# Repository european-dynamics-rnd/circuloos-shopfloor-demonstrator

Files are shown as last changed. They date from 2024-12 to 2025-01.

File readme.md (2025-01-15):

# CIRCULOOS Shopfloor Demo

The current repo is a collection of hardware and software compoment ment to simulate the jurney of the measurements of a shopfloor to a local RAMP IIoT instance (on a RasberyPi) and on the centalazed CIRCULOOS Data platform.
The demo consist of a full end to end solution ie from the sensor to the communication inside the shopfloor to the local RAMP IIoT instance and to the centalazed CIRCULOOS Data platform.

# Troubleshoot
See Troubleshoot

## Measurements
The following measurements (from various sensors) are included:
- Air temperature (BME680)
- Air hummidity (BME680)
- Air presure (BME680)
- Surface temperature (Pt100, k-type thermocuple)
- Inductive proximity sensor
- Weight
- Colour

## Shopfloor communication protocols 
The following communication protocols are incuded:
- CAN
- RS485 
- MQTT 
- I2C

# Sensor nodes 

The base embeded computational unit for each node is the module based on ESP32 by Olimex.

A list of the different node with each sensor can be foound on [system.md](./system.md)

## Diagram
diagram

# Demos

## sensor_node_1_scale_and_colour_over_RS485

The sensor node/ESP32  is designed to simulate a station that measures the weight and identifies the color of an item. It consists of an LCD, two buttons, a scale, and color sensors.

The user begins the procedure by pressing a button to activate the color sensor. They then position the sensor over the material to be identified. The detected color will be displayed on the LCD. Once the user finalizes the procedure, they release the button.

Next, the material (up to 1 kg) is placed on the scale. After waiting for the measurement to stabilize, the user gently presses the button.

The data is then sent via RS-485 to the Raspberry Pi. An python script reads the data from the serial and transform it on a NGSI-LD entity where it becomes available on the local CIRCULOOS data platform.

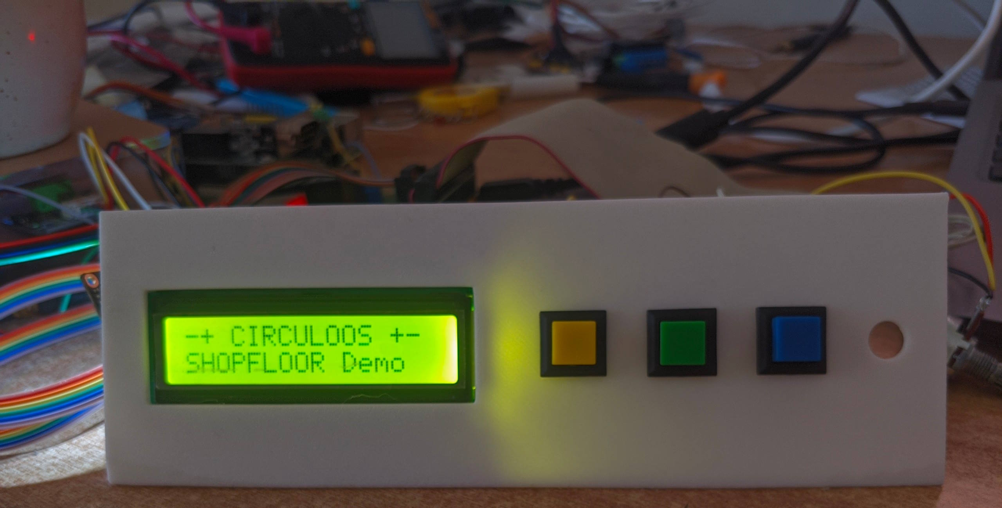
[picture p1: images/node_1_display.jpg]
node_1_display

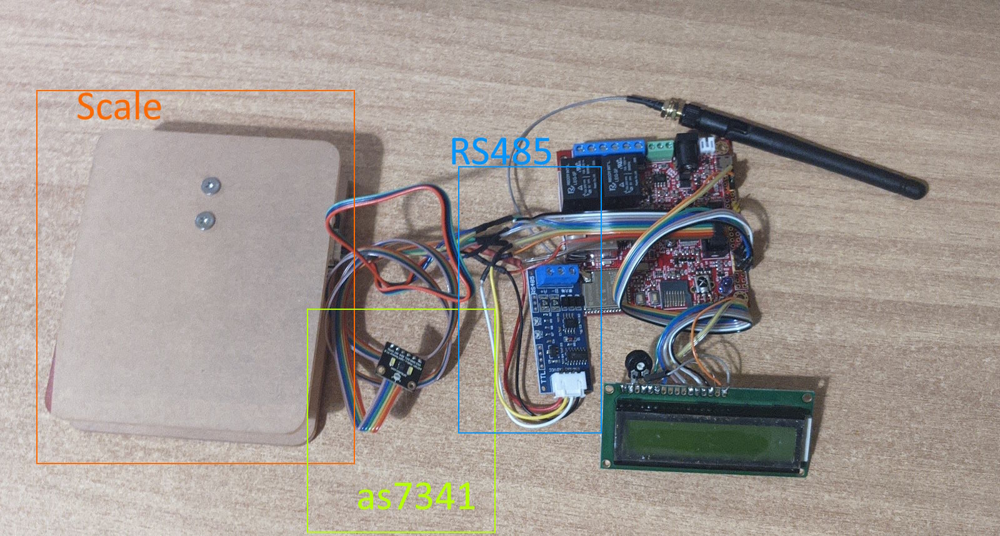
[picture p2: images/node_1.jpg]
node_1


## sensor_node_2_environmental_over_wifi

The node/ESP32 reads the external BME680 sensor via I2C every 10min, transform the measurements into a json and send it to a local MQTT Broker, running on the RasberyPi.
The json message it is read by the IoTAgent and becomes avalable to the local CIRCULOOS data platform. 

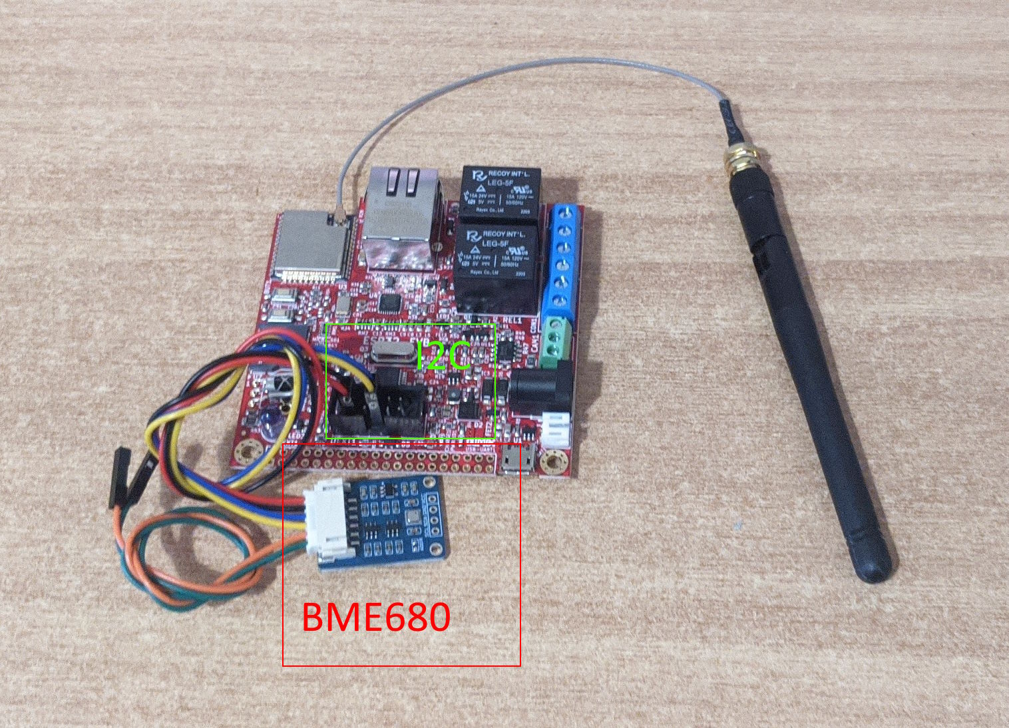
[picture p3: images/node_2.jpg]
node_2


## sensor_node_3_temperature_over_can

The node/ESP32 reads the external Pt100 and a K-type thermocouple every 10min, and sends the measurements via CAN bus to the Raspberry Pi. 

An python script reads the data from the serial and transform it on a NGSI-LD entity where it becomes available on the local CIRCULOOS data platform.

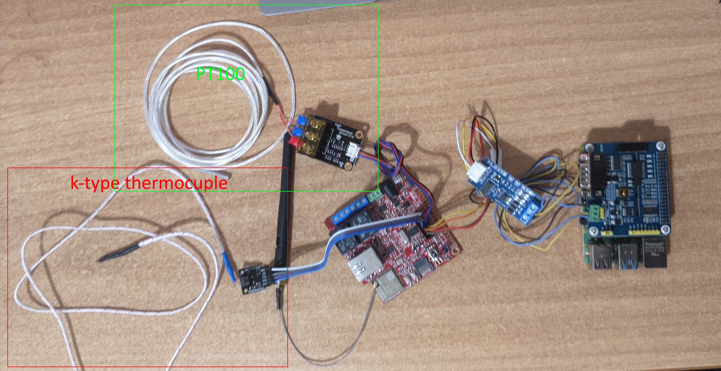
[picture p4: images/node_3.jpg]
node_3


<br />
<br />
<br />
<br />

Copyright © 2023-2024 European Dynamics Luxembourg S.A.

Licensed under the EUPL, Version 1.2.
You may not use this work except in compliance with the License.
You may obtain a copy of the License at https://joinup.ec.europa.eu/collection/eupl/eupl-text-eupl-12 

Unless required by applicable law or agreed to in writing, software distributed under the License is distributed on an "AS IS" BASIS,
WITHOUT WARRANTIES OR CONDITIONS OF ANY KIND, either express or implied. See the License for the specific language governing permissions and limitations under the License.

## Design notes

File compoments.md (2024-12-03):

# Main computation unit
## RaspberryPi  5
https://grobotronics.com/raspberry-pi-5-8gb.html  or https://www.hellasdigital.gr/go-create/raspberry-and-accessories/raspberry-pi-5-and-accessories/raspberry-pi-5/raspberry-pi-5-8gb/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
https://grobotronics.com/aluminum-case-for-raspberry-pi-5-temperature-controlled-fan.html

**OR** 

## RaspberryPi  4
https://grobotronics.com/raspberry-pi-4-model-b-8gb.html
https://grobotronics.com/case-for-raspberry-pi-4-with-cooling-fan-black-clear.html

## RasberyPi misc
https://grobotronics.com/hdmi-to-micro-hdmi-male-1.8m-black.html
https://grobotronics.com/power-supply-for-raspberry-pi-5-27w-type-c.html
https://grobotronics.com/sandisk-ultra-microsdxc-128gb-class-10-140mb-s-sd-adapter.html

# ESP32 modules
https://www.olimex.com/Products/IoT/ESP32/ESP32-EVB/open-source-hardware ESP32-EVB-EA-IND  x4

# sensors
https://grobotronics.com/fermion-as7341-11-channel-visible-light-sensor.html
https://grobotronics.com/inductive-proximity-sensor-12mm-lj12a3-4-z-ex.html

# Temperature sensors

https://grobotronics.com/waveshare-environmental-sensor-bme680.html x4

https://grobotronics.com/gravity-analog-high-temperature-sensor-30350c.html
https://grobotronics.com/pimoroni-mcp9600-thermocouple-amplifier-breakout.html
https://grobotronics.com/pimoroni-braided-k-type-thermocouple.html

# Scale
https://grobotronics.com/gravity-i2c-1kg-weight-sensor-kit-hx711.html

# CAN bus
https://www.waveshare.com/product/2-ch-can-hat-plus.htm
https://www.hellasdigital.gr/go-create/raspberry-and-accessories/raspberry-pi-4-and-accessories/2-channel-isolated-can-expansion-hat-for-raspberry-pi-board/

# RS485 modules
https://grobotronics.com/waveshare-isolated-rs485-rs232-hat-spi-control.html
https://grobotronics.com/ttl-to-rs485-module.html x3

# Misc
https://grobotronics.com/dc-power-plug-5.5-x-2.1mm-barrel-plugable-screw-terminal.html  x4
https://grobotronics.com/hook-up-wire-22awg-0.32mm2-assortment-stranded.html
https://grobotronics.com/power-supply-5vdc-2a-clw-eb-output-5.5x2.1.html x4

# Current sensor
https://grobotronics.com/gravity-analog-ac-current-sensor-10a.html

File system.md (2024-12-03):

# RAMP IIoT computer

## Components 
- RaspberryPi 5 8GB
- Power supply 
- Case with fun
- SD card
## Communication interfaces
- RS485 ([waveshare](https://grobotronics.com/waveshare-isolated-rs485-rs232-hat-spi-control.html))
- CAN bus ([waveshare](https://www.waveshare.com/product/2-ch-can-hat-plus.htm))

### Optimal
HDMI to micro

# Sensor Node #1 scale and colour  - RS485/Modubus
- ESP32 ([olimex](https://www.olimex.com/Products/IoT/ESP32/ESP32-EVB/open-source-hardware))
- Scale kit ([gravity](https://grobotronics.com/gravity-i2c-1kg-weight-sensor-kit-hx711.html))
- Color sensors ([AS7341](https://grobotronics.com/fermion-as7341-11-channel-visible-light-sensor.html))
- TTL to RS485 module ([module](https://grobotronics.com/ttl-to-rs485-module.html))

# Sensor Node #2 Environmental mqtt over wifi
- ESP32 ([olimex](https://www.olimex.com/Products/IoT/ESP32/ESP32-EVB/open-source-hardware))
- Temperature, RH, Barometric Pressure ([BME680](https://grobotronics.com/waveshare-environmental-sensor-bme680.html) )
- PT1000 ([module](https://grobotronics.com/gravity-analog-high-temperature-sensor-30350c.html))
- K-type thermocouple ([modeule](https://grobotronics.com/pimoroni-mcp9600-thermocouple-amplifier-breakout.html))

# Sensor Node #3 Temperature - CAN bus
- ESP32 ([olimex](https://www.olimex.com/Products/IoT/ESP32/ESP32-EVB/open-source-hardware))
- PT1000 ([module](https://grobotronics.com/gravity-analog-high-temperature-sensor-30350c.html))
- K-type thermocouple ([modeule](https://grobotronics.com/pimoroni-mcp9600-thermocouple-amplifier-breakout.html))
- Inductive Proximity ([module](https://grobotronics.com/inductive-proximity-sensor-12mm-lj12a3-4-z-ex.html))

# Sensor Node #4 - OPC UA Server over wifi
- ESP32 ([olimex](https://www.olimex.com/Products/IoT/ESP32/ESP32-EVB/open-source-hardware))
- Temperature, RH, Barometric Pressure ([BME680](https://grobotronics.com/waveshare-environmental-sensor-bme680.html) )

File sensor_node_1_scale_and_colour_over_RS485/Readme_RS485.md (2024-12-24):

# RS485 encoding

For the demo a easy encoding schme is used for the transfer of data from the ESP32 to the rasberryPI.

## for scale and colour sensors, type 1

Message: #1;weight_in_gr;as7341_ADF2;as7341_ADF4;as7341_ADF3;as7341_ADF5;as7341_ADF7;as7341_ADF8;as7341_ADCLEAR;as7341_ADF6;as7341_ADNIR#

see [sample_data.txt](./sample_data.txt) for more examples.

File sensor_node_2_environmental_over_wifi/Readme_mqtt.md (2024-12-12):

# Connecting a MQTT topic with Agent
The MQTT topic that listen is /json/BME680KEYas32r/node-002/attrs so /json/<<apikey>>/<<device_id>>/attrs

apikey is set on [provisioning_service.sh](../circuloos-data-platform/nodes/provisioning_service.sh) from on the circuloos-data-platform ie BME680KEYas32r
device_id ie node-002

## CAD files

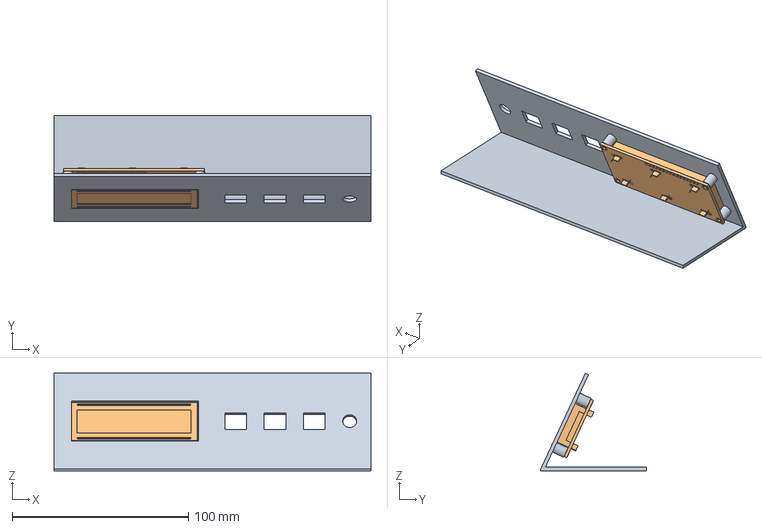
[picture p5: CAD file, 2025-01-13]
sensor_node_1_scale_and_colour_over_RS485/3d_model/stand.FCStd
180.0 x 60.0 x 55.4 mm
JHD162A1337

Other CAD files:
sensor_node_1_scale_and_colour_over_RS485/3d_model/stand.3mf

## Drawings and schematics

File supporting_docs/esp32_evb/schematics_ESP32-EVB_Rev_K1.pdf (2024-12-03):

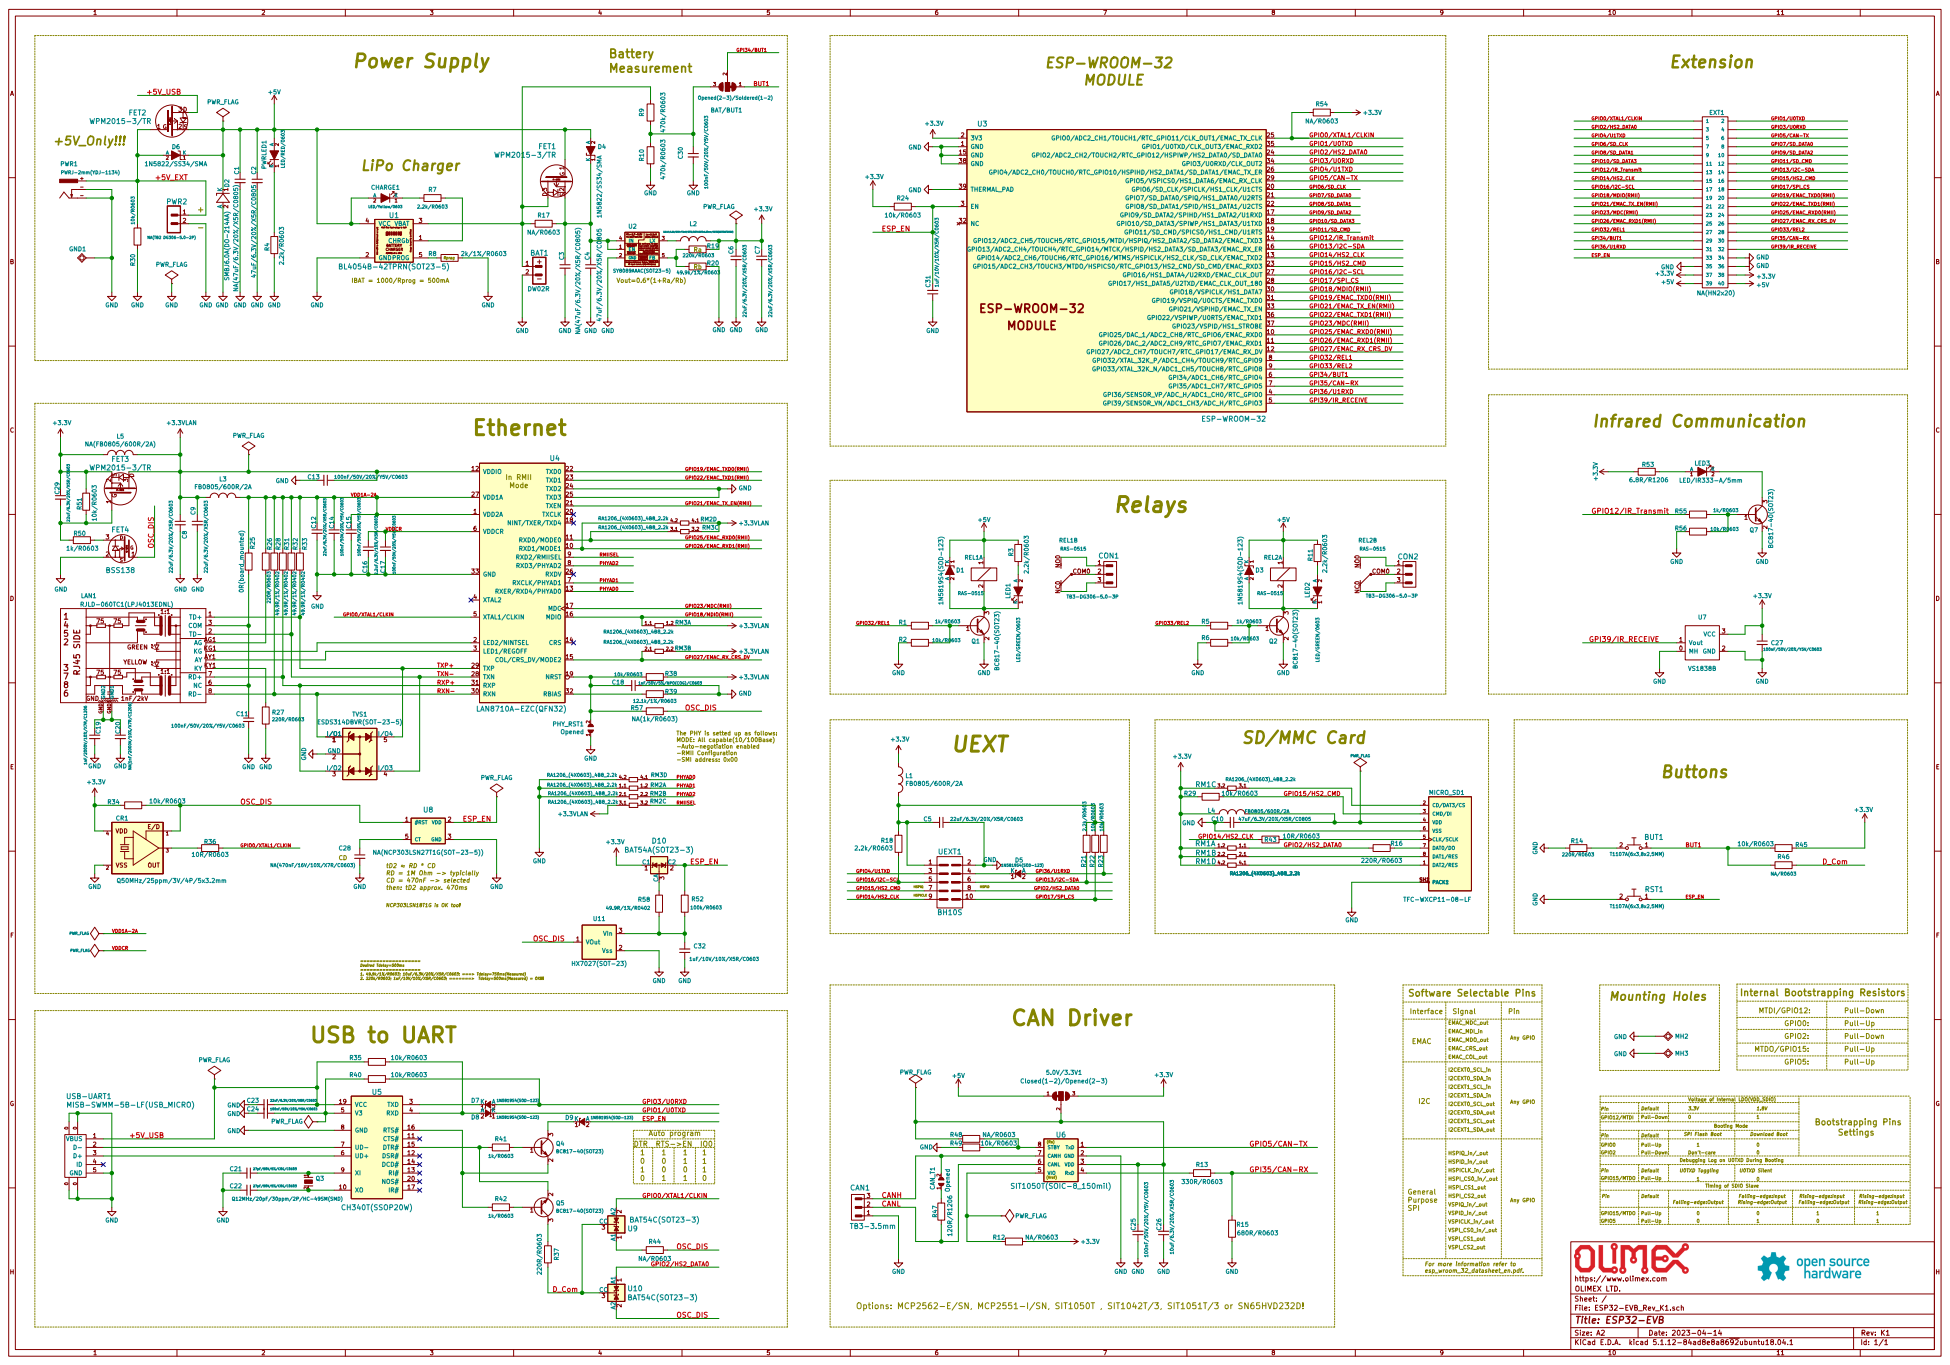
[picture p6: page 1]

Vout=0.6*(1+Ra/Rb) EN 1 GND 2

Do not float. Enable control. FB Input Current, I(FB)=50nA(max) Feedback Reference Voltage, V(REF)=0.6V

load current capability! Lx=2.2uH

ESP_EN GPIO19/EMAC_TXD0(RMII) RXN- RXP+ TXN- TXP+ OSC_DIS
PWR_FLAG

GPIO22/EMAC_TXD1(RMII) GPIO21/EMAC_TX_EN(RMII) GPIO25/EMAC_RXD0(RMII) GPIO25/EMAC_RXD0(RMII) GPIO18/MDIO(RMII) GPIO27/EMAC_RX_CRS_DV

1 2PHY_RST1 Opened C18 1nF/50V/5%/NPO(COG)/C0603 R39 GND

The PHY is setted up as follows: MODE: All capable(10/100Base)
-Auto-negotiation enabled
-RMII Configuration
2 CA3 D10 BAT54A(SOT23-3) GND

RD = 1M Ohm -> typiclally CD = 470nF -> selected

then: tD2 approx. 470ms USB to UART

Voltage of Internal LDO(VDD_SDIO) Signal Software Selectable Pins

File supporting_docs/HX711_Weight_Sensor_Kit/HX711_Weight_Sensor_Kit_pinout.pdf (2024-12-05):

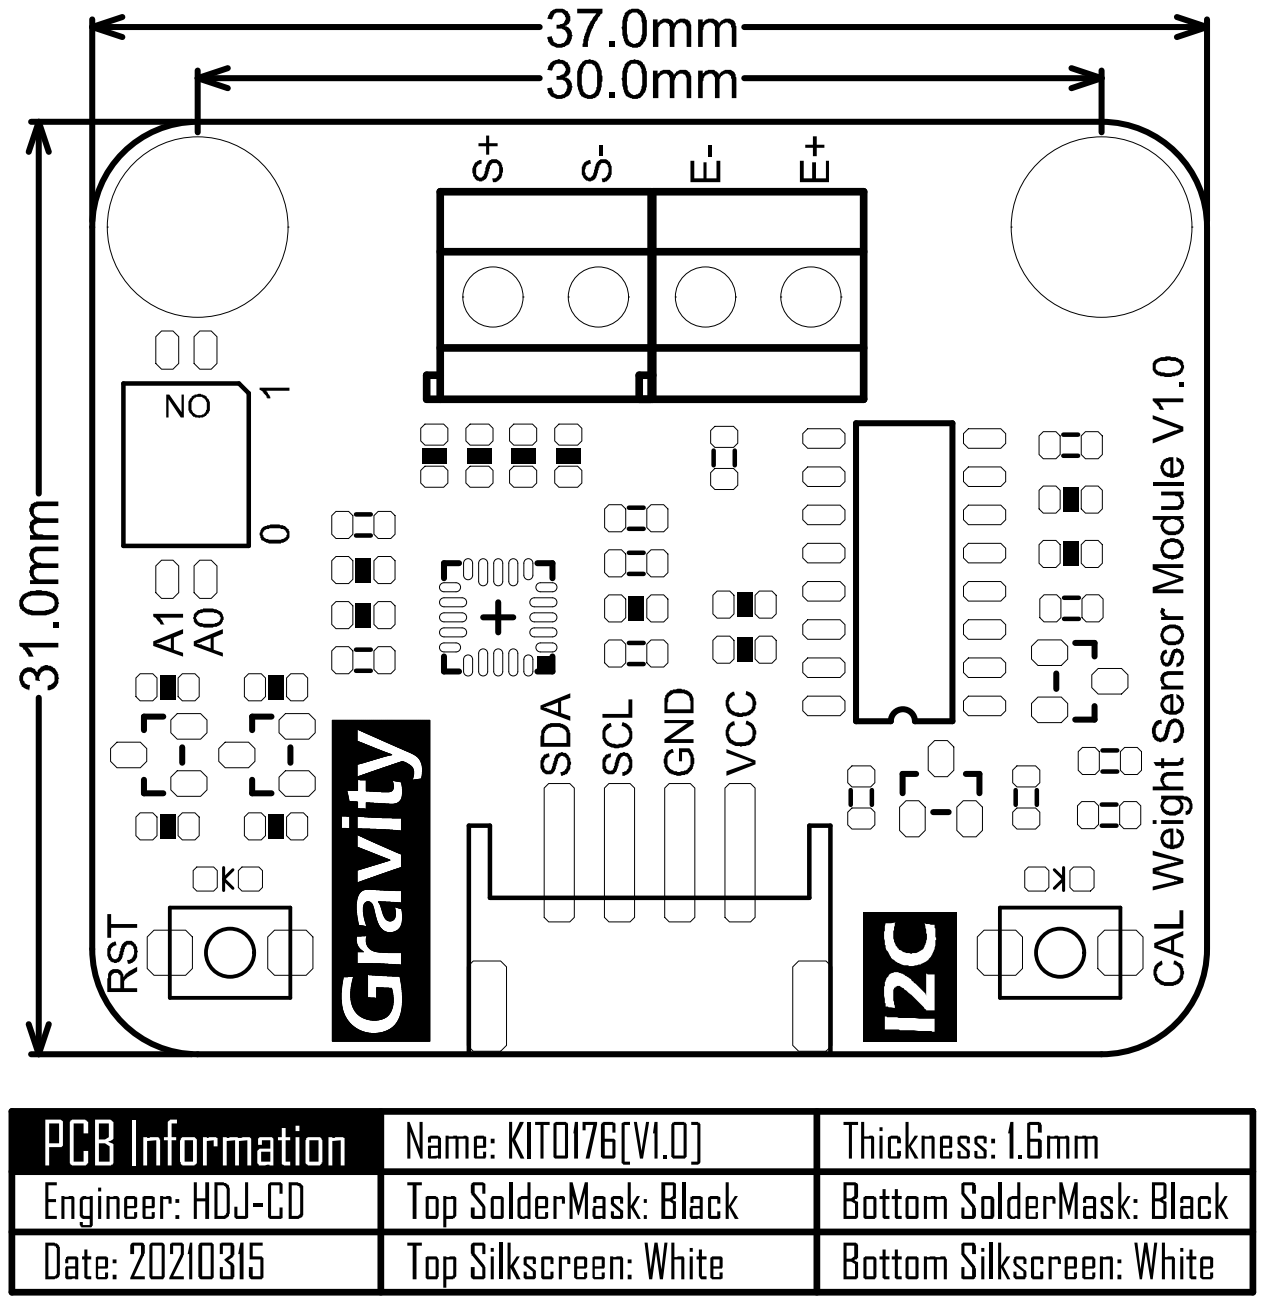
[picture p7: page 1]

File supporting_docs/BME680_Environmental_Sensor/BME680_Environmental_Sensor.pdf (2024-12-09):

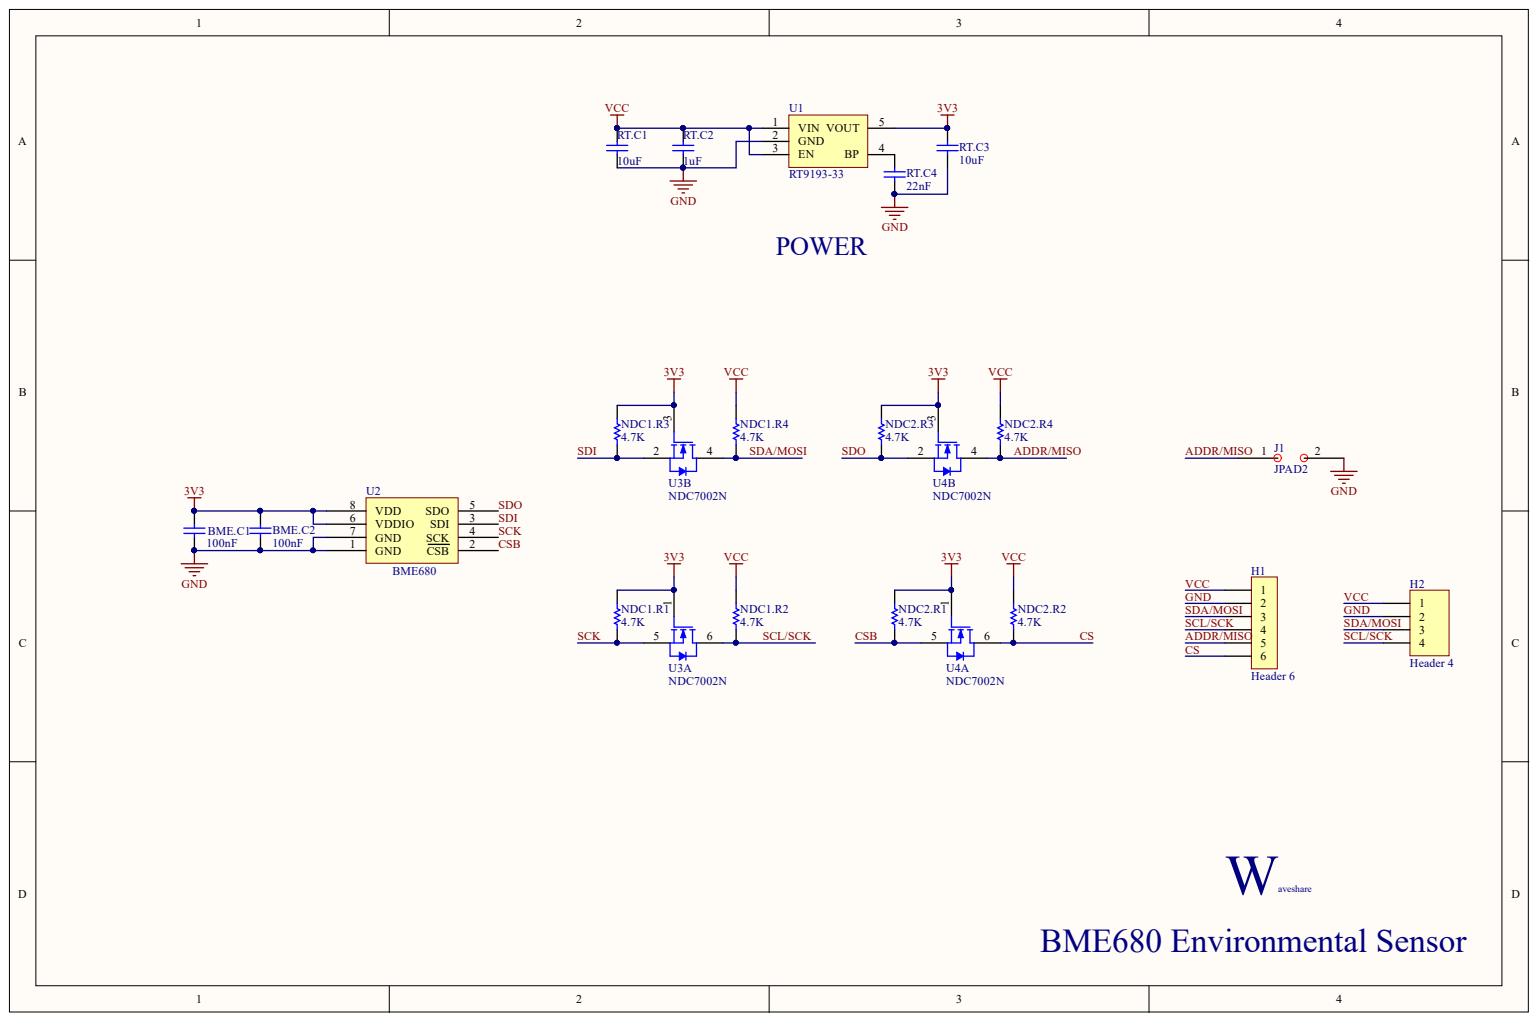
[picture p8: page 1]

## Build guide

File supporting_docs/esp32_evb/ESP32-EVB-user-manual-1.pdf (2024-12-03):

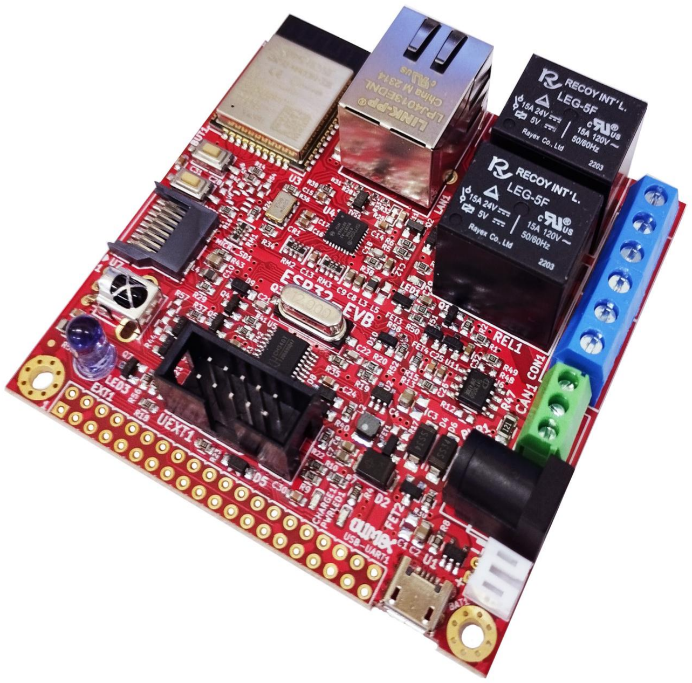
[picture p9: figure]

# ESP32-EVB

# User Manual

Document revision 1.0, August 2024 | www. (http://www.olimex.com/) o (http://www.olimex.com/) limex.com (http://www.olimex.com/)

## Table of Contents

## 1. What is ESP32-EVB

ESP32-EVB is a mature Open Source Hardware development board that incorporates n ESP32 module. The ESP32-EVB board is designed and manufactured by Olimex, while the ESP32 module is designed and manufactured by Espressif systems. The ESP32 modules are extremely popular WIFI/BT modules due to their size, price, and very good documentation.

The ESP32-EVB board has the following features:
- ESP32-WROOM-32E or ESP32-WROOM-32UE module (depending on variant) with WiFi, BLE connectivity
- USB micro connector for powering and programming
- Built-in CH340T programmer for Arduino and ESP-IDF
- Ethernet 100Mb interface with ETH8710A
- MicroSD card
- 2x10A/250VAC (15A/120VAC 15A/24VDC) relays with connectors and status LEDs
- CAN transceiver and interface
- IR received and transmitter, up to 5 meters distance
- LiPo charger for stand alone operation during power breaks with 4 status LEDs
- Power jack for external power supply, 5V DC
- UEXT connector to for expansion modules
- Reset and user buttons
- GPIO 40 pin connector with all ESP32 ports
- Dimensions: (75x75)mm ~ (2.95x2.95)"
- Optional external antenna (-EA)
- Industrial grade -40+85C version available (-IND)

### 1.1 ESP32-EVB variants

The board has 4 variants – ESP32-EVB, ESP32-EVB-EA, ESP32-EVB-EA-IND, ESP32-EVB-IND. The base variant ESP32-EVB works in commercial temperature range (0-70 degrees C) and has onmodule antenna.

ESP32-EVB and ESP32-EVB-IND come with ESP32-WROOM-32E module;
ESP32-EVB-EA and ESP32-EVB-EA-IND come with ESP32-WROOM-32UE and external antenna; ESP32-EVB and ESP32-EVB-EA work in the commercial temperature range 0-70C; ESP32-EVB-IND and ESP32-EVB-EA-IND are functionally identical, but have all components rated for operating in the industrial temperature range -40+85C.

### 1.2 Board use requirements

You only need a fitting USB cable and a personal computer. The board requires USB micro connector. Usually only such cable is required:

https://www.olimex.com/Products/Components/Cables/USB-CABLE-A-MICRO-1.8M/

The computer needs software compatible with ESP32 modules. Most commonly used tools are ESP-IDF and Arduino IDE with ESP32 package. You can use ESP32-EVB with any software tool that supports the main ESP32 module.

### 1.3 ESP32-EVB Open Source Licenses

ESP32-EVB is Open Source Hardware, listed in OSHWA.org here: https://certification.oshwa.org/bg000011.html

The hardware files are released under CERN OSHW license. (https://github.com/OLIMEX/USB-gLINK/blob/master/cern_ohl_s_v2.pdf)
The software is released under GPL 3 license. (https://github.com/OLIMEX/USB-gLINK/blob/master/LICENSE)
The documentation is released under CC BY-SA 3.0 (https://creativecommons.org/licenses/by-sa/3.0/) license.

## 2. ESP32-EVB general layout

ESP32
module

Ethernet
commector | Relay 2

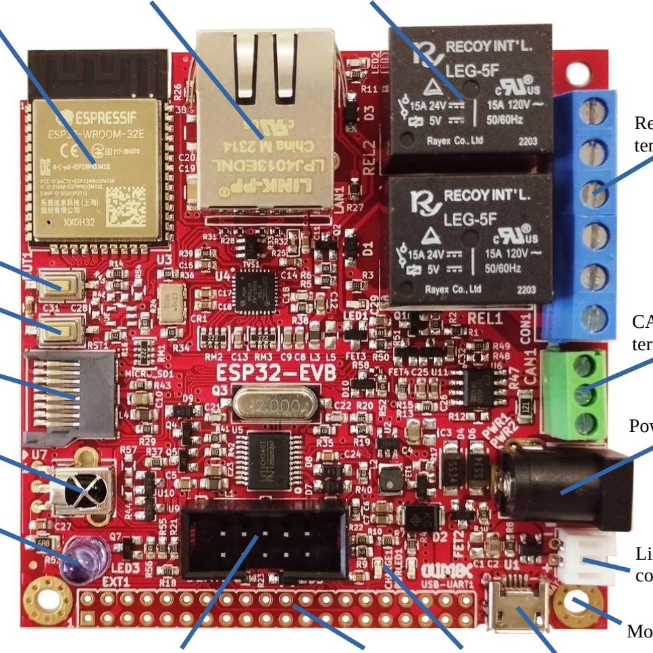
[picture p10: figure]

UEXT
connector

EXT header

Relay
terminals

CAN
terminal

Power jack

Li-Po
connector

Mount hole

Battery
LEDs Micro USB

User
button
Reset
button

MicroSD
card holder

Infrared

User LED

## 3. ESP32-EVB power supply and consumption

ESP32-EVB typically consumes between 40mA and 200mA of current depending on the software. The board can consume much less using the power saving modes.

The absolute maximum power ESP32-EVB can draw from the power supply would be the determined by the maximum input of the regulator on the power input line. Of course, consider that on-board peripherals and the main module would use some of that current. There are two major cases:

1) If you power the board from the PWR jack or the USB – > the regulator is SY8089 can output maximum 2000mA continuously
2) If you power the board from battery –> the Li-Po battery charger MCP73833 can output up to 1200mA

## 4. ESP32-EVB schematics and dimensions

ESP32-EVB was designed with KiCAD (free and open-source CAD tool). ESP32-EVB schematics and sources can be found at GitHub here:

https://github.com/OLIMEX/ESP32-EVB/tree/master/HARDWARE

There are also PDF exports if you don’t want to install KiCAD.

Board dimensions can be found here:

https://github.com/OLIMEX/ESP32-EVB/blob/master/HARDWARE/ESP32-EVB_dimensions.pdf

## 5. ESP32-EVB pinout description:

The board doesn’t have many free pins, most of the free pins are available at the UEXT connector. Even at the UEXT some of the pins are multiplex with the SD card, meaning that if you have SD card attached these won’t work.

The ESP32 chip has very good multiplexer so you can set the free GPIO pins for alternative functions via software means.

The SD card interface is in 1-bit eMMC mode.

The CAN is controlled by SIT1050T (different hardware revisions might use different CAN transceiver chip) and by default the CAN terminating resistor is disconnected. If this is end CAN device (or if you just have 2 CAN devices on that bus) it is good idea to close it. Solder CAN_T1 jumper to connect the terminating resistor.

## 6. ESP32-EVB software installation

Esspresif guide for Arduino IDE installation (https://docs.espressif.com/projects/arduino-esp32/en/latest/installing.html) – after installation – there is own entry for the board, it should be listed as OLIMEX ESP32-EVB in the board selection
Espressif ESP-IDF installation (https://github.com/espressif/esp-idf)
Esspressif guide for PlatformIO installation. (https://docs.espressif.com/projects/arduino-esp32/en/latest/installing.html)
Olimex provides some ESP-IDF and Arduino examples here: https://github.com/OLIMEX/ESP32-EVB/tree/master/SOFTWARE

## 7. Document revision history

Revision 1.0 August 2024

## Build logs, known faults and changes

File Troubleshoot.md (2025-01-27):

# Orion, mintaka restart and mongodb is not live

```console
cd /circuloos-data-platform
./service stop
docker run --privileged --rm tonistiigi/binfmt --install all
./service start
 ```

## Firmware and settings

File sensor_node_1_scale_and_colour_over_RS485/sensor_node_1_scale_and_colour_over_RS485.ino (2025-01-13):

/*
ESP32 used pins:
2  -> AS7341_GPIO_0, IDC10
4  -> RS485_TX, IDC10
13 -> I2C_SDA, IDC10 + EXT_1
14 -> Potantiometer, EXT_1
15 -> AS7341_INT, IDC10
16 -> I2C_SCL, IDC10 + EXT_1
18  -> Blue button, EXT_1
19 -> Green button, EXT_1
22 -> Yellow button, EXT_1
36 -> RS485_RX, IDC10

*/
#include <Wire.h>
#include <LiquidCrystal_I2C.h>
LiquidCrystal_I2C lcd(0x27, 16, 2);


#include <math.h>
// #include <ezButton.h>  // by ArduinoGetStarted.com

#define BUTTON_SCALE 22          //yellow button
#define BUTTON_AS7341 19         // green button
#define BUTTON_SEND_DATA 18      //blue buttoon
#define AS7341_POTENTIOMETER 14  // potentiometer for AS7341 LED level

#include "DFRobot_HX711_I2C.h"
#include "DFRobot_AS7341.h"

//DFRobot_HX711_I2C MyScale(&Wire,/*addr=*/0x64);
DFRobot_HX711_I2C MyScale;
float weight = -1;
bool is_scale_calibrated=false ; 


DFRobot_AS7341 as7341;
int as7341_led_level = 1;

struct t_as7341 {
  int spectralData[8];
  String as7341_string;
};

t_as7341 as7341_data;
String hex_color;
#define RXD1 36
#define TXD1 4

String final_resault = "";


void setup() {
  Serial.begin(115200);
  Serial1.begin(9600, SERIAL_8E1, RXD1, TXD1);
  startup_as7341();
  setup_buttons();
  setup_lcd();
  pinMode(AS7341_POTENTIOMETER, INPUT);
  Serial.println("starting....");
}

void setup_lcd() {
  lcd.init();  // initialize the lcd
  lcd.backlight();

  lcd.home();

  lcd.setCursor(0, 0);
  // lcd.print("1234567890123456"
  lcd.print("-+ CIRCULOOS +-");
  lcd.setCursor(0, 1);
  lcd.print("SHOPFLOOR Demo");
}

void setup_buttons() {
  pinMode(BUTTON_SCALE, INPUT);
  pinMode(BUTTON_AS7341, INPUT);
  pinMode(BUTTON_SEND_DATA, INPUT);
}

void startup_as7341() {
  while (as7341.begin() != 0) {
    Serial.println("IIC init failed, please check if the wire connection is correct");
    delay(1000);
  }
  //Integration time = (ATIME + 1) x (ASTEP + 1) x 2.78µs
  //Set the value of register ATIME(1-255), through which the value of Integration time can be calculated. The value represents the time that must be spent during data reading.
  as7341.setAtime(29);
  //Set the value of register ASTEP(0-65534), through which the value of Integration time can be calculated. The value represents the time that must be spent during data reading.
  as7341.setAstep(1000);
  //Set gain value(0~10 corresponds to X0.5,X1,X2,X4,X8,X16,X32,X64,X128,X256,X512)
  as7341.setAGAIN(2);

  // //  Enable LED
  as7341.enableLed(true);
  // //  Set pin current to control brightness (1~20 corresponds to current 4mA,6mA,8mA,10mA,12mA,......,42mA)
  as7341.controlLed(as7341_led_level);
}

t_as7341 read_as7341(bool detailed_print) {
  t_as7341 local_as7341_data;

  DFRobot_AS7341::sModeOneData_t data1;
  DFRobot_AS7341::sModeTwoData_t data2;

  //Start spectrum measurement
  //Channel mapping mode: 1.eF1F4ClearNIR,2.eF5F8ClearNIR
  as7341.startMeasure(as7341.eF1F4ClearNIR);
  //Read the value of sensor data channel 0~5, under eF1F4ClearNIR
  data1 = as7341.readSpectralDataOne();
  as7341.startMeasure(as7341.eF5F8ClearNIR);
  //Read the value of sensor data channel 0~5, under eF5F8ClearNIR
  data2 = as7341.readSpectralDataTwo();
  if (detailed_print) {
    Serial.print("F1(405-425nm):");
    Serial.println(data1.ADF1);
    Serial.print("F2(435-455nm):");
    Serial.println(data1.ADF2);
    Serial.print("F3(470-490nm):");
    Serial.println(data1.ADF3);
    Serial.print("F4(505-525nm):");
    Serial.println(data1.ADF4);

    Serial.print("F5(545-565nm):");
    Serial.println(data2.ADF5);
    Serial.print("F6(580-600nm):");
    Serial.println(data2.ADF6);
    Serial.print("F7(620-640nm):");
    Serial.println(data2.ADF7);
    Serial.print("F8(670-690nm):");
    Serial.println(data2.ADF8);
    Serial.print("Clear:");
    Serial.println(data2.ADCLEAR);
    Serial.print("NIR:");
    Serial.println(data2.ADNIR);
  }
  local_as7341_data.as7341_string = String(data1.ADF2) + ";" + String(data1.ADF4) + ";" + String(data1.ADF3) + ";" + String(data2.ADF5) + ";" + String(data2.ADF7) + ";" + String(data2.ADF8) + ";" + String(data2.ADCLEAR) + ";" + String(data2.ADF6) + ";" + String(data2.ADNIR);

  local_as7341_data.spectralData[0] = data1.ADF1;
  local_as7341_data.spectralData[1] = data1.ADF2;
  local_as7341_data.spectralData[2] = data1.ADF3;
  local_as7341_data.spectralData[3] = data1.ADF4;
  local_as7341_data.spectralData[4] = data2.ADF5;
  local_as7341_data.spectralData[5] = data2.ADF6;
  local_as7341_data.spectralData[6] = data2.ADF7;
  local_as7341_data.spectralData[7] = data2.ADF8;


  return local_as7341_data;
}

String calculateColor(int spectralData[]) {
  // Define RGB values for each band based on wavelengths
  float wavelengthToRGB[8][3] = {
    { 0.5, 0, 1 },  // F1 (405-425nm): violet
    { 0, 0, 1 },    // F2 (435-455nm): blue
    { 0, 0.5, 1 },  // F3 (470-490nm): blue-cyan
    { 0, 1, 0.5 },  // F4 (505-525nm): green-cyan
    { 0, 1, 0 },    // F5 (545-565nm): green
    { 1, 1, 0 },    // F6 (580-600nm): yellow
    { 1, 0.5, 0 },  // F7 (620-640nm): orange
    { 1, 0, 0 }     // F8 (670-690nm): red
  };

  // Find the maximum spectral value for normalization
  int maxValue = 0;
  for (int i = 0; i < 8; i++) {
    if (spectralData[i] > maxValue) {
      maxValue = spectralData[i];
    }
  }

  // Normalize and calculate weighted RGB
  float weightedRGB[3] = { 0, 0, 0 };
  for (int i = 0; i < 8; i++) {
    float normalizedValue = (float)spectralData[i] / maxValue;
    weightedRGB[0] += normalizedValue * wavelengthToRGB[i][0];
    weightedRGB[1] += normalizedValue * wavelengthToRGB[i][1];
    weightedRGB[2] += normalizedValue * wavelengthToRGB[i][2];
  }

  // Clamp RGB values to [0, 1]
  for (int i = 0; i < 3; i++) {
    if (weightedRGB[i] > 1) {
      weightedRGB[i] = 1;
    }
  }

  // Convert to HEX color format
  int r = round(weightedRGB[0] * 255);
  int g = round(weightedRGB[1] * 255);
  int b = round(weightedRGB[2] * 255);

  char hexColor[8];
  sprintf(hexColor, "#%02X%02X%02X", r, g, b);
  // Show to LCD

  return String(hexColor);
}


void calibreate_scale() {
  while (!MyScale.begin()) {
    Serial.println("The initialization of the chip is failed, please confirm whether the chip connection is correct");
    lcd.clear();
    lcd.setCursor(0, 0);
    lcd.print("SCALE init probl");
    delay(1000);
  }
  //Set the calibration weight when the weight sensor module is automatically calibrated (g)
  MyScale.setCalWeight(100);
  // Set the trigger threshold (G) for automatic calibration of the weight sensor module. When only the weight of the object on the scale is greater than this value, the module will start the calibration process
  // This value cannot be greater than the calibration weight of the setCalWeight() setting
  MyScale.setThreshold(30);

  //Start sensor calibration
  Serial.println("Please put the object within 5S");
  lcd.clear();
  lcd.setCursor(0, 0);
  lcd.print("Please put the ");
  lcd.setCursor(0, 1);
  lcd.print("object within 5S");

  MyScale.enableCal();
  long time1 = millis();
  //Wait for sensor calibration to complete
  while (!MyScale.getCalFlag()) {
    delay(1000);
    if ((millis() - time1) > 7000) {
      Serial.println("The calibration failed this time, and no object is detected within 5S. The last calibration value will be used.");
      lcd.clear();
      lcd.setCursor(0, 0);
      lcd.print("The calibration failed");
      break;
    }
  }
  //Obtain the calibration value. The accurate calibration value can be obtained after the calibration operation is completed
  Serial.print("the calibration value of the sensor is: ");
  Serial.println(MyScale.getCalibration());
  MyScale.setCalibration(MyScale.getCalibration());
}

float read_scale() {
  float _weight = MyScale.readWeight();
  // Show to LCD
  lcd.clear();
  lcd.setCursor(0, 0);
  lcd.print("weight is: ");
  lcd.setCursor(0, 1);
  if (_weight > 0.5) {
    lcd.print(_weight, 1);
  } else {
    lcd.print(0, 1);
  }
  lcd.print(" gr");
  return _weight;
}



void loop() {
  if (digitalRead(BUTTON_AS7341) == LOW) {
    Serial.println("BUTTON_AS7341");
    Serial.print("led_level: ");
    Serial.println(as7341_led_level);

    as7341_data = read_as7341(false);
    Serial.println(as7341_data.as7341_string);
    hex_color = calculateColor(as7341_data.spectralData);
    Serial.print("Hex color: ");
    Serial.println(hex_color);
    lcd.clear();
    lcd.setCursor(0, 0);
    lcd.print("Hex color:");
    lcd.setCursor(0, 1);
    lcd.print(hex_color);
    delay(10);
  }

  if (digitalRead(BUTTON_SCALE) == LOW) {
    Serial.println(" BUTTON_SCALE");
    if (!is_scale_calibrated) {
      calibreate_scale();
      is_scale_calibrated=true;
    }
    weight = read_scale();
  }

  if (digitalRead(BUTTON_SEND_DATA) == LOW) {
    final_resault="#1;"+String(weight) + ";" + as7341_data.as7341_string+ "#";
    Serial.println(final_resault);
    Serial1.println(final_resault);
    lcd.clear();
    lcd.setCursor(0, 0);
    lcd.print("Sending Data:");
    lcd.setCursor(0, 1);
    lcd.print(final_resault);
  }

  as7341_led_level = map(analogRead(AS7341_POTENTIOMETER), 100, 4095, 0, 18);
  as7341.controlLed(as7341_led_level);

  delay(10);
}

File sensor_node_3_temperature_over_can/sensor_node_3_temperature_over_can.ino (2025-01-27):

#include "Seeed_MCP9600.h"
#include <DFRobotHighTemperatureSensor.h>

#include <ESP32-TWAI-CAN.hpp>
#define CAN_TX 5  // Connects to CTX
#define CAN_RX 35  // Connects to CRX


CanFrame rxFrame;  // Create frame to read

MCP9600 sensor(0x66);
float mcp9600_temp = 0;
int int_mcp9600_temp = 0;

// Pt1000
const float voltageRef = 3.300;                                     //Set reference voltage,you need test your IOREF voltage.
int HighTemperaturePin = 15;                                        // pin 15-> adc3                           //Setting pin
DFRobotHighTemperature PT100 = DFRobotHighTemperature(voltageRef);  //Define an PT100 object
int pt100_temp = 0;
float_pt100_temp=0;

err_t mcp9600_sensor_basic_config() {
  err_t ret = NO_ERROR;
  CHECK_RESULT(ret, sensor.set_filt_coefficients(FILT_MID));
  CHECK_RESULT(ret, sensor.set_cold_junc_resolution(COLD_JUNC_RESOLUTION_0_25));
  CHECK_RESULT(ret, sensor.set_ADC_meas_resolution(ADC_14BIT_RESOLUTION));
  CHECK_RESULT(ret, sensor.set_burst_mode_samp(BURST_32_SAMPLE));
  CHECK_RESULT(ret, sensor.set_sensor_mode(NORMAL_OPERATION));
  return ret;
}


err_t mcp9600_get_temperature(float* value) {
  err_t ret = NO_ERROR;
  float hot_junc = 0;
  float junc_delta = 0;
  float cold_junc = 0;
  CHECK_RESULT(ret, sensor.read_hot_junc(&hot_junc));
  CHECK_RESULT(ret, sensor.read_junc_temp_delta(&junc_delta));

  CHECK_RESULT(ret, sensor.read_cold_junc(&cold_junc));

  // Serial.print("hot junc=");
  // Serial.println(hot_junc);
  // Serial.print("junc_delta=");
  // Serial.println(junc_delta);
  // Serial.print("cold_junc=");
  // Serial.println(cold_junc);

  *value = hot_junc;

  return ret;
}

void setup_mcp9600() {

  Serial.println("Serial start!!");
  if (sensor.init(THER_TYPE_K)) {
    Serial.println("sensor init failed!!");
  }
  mcp9600_sensor_basic_config();
}

void setup_CAN() {
  // Set the pins
  ESP32Can.setPins(CAN_TX, CAN_RX);

  // Start the CAN bus at 500 kbps
  if (ESP32Can.begin(ESP32Can.convertSpeed(500))) {
    Serial.println("CAN bus started!");
  } else {
    Serial.println("CAN bus failed!");
  }
}

void setup() {
  Serial.begin(115200);
  delay(10);
  setup_mcp9600();
  setup_CAN() ;
}


void send_measurement_can(int temp1, int temp2) {
  // Max temp  -327.68 to 327.67
  CanFrame tempFrame = { 0 };
  tempFrame.identifier = 0xED1;
  // Split number1 into 2 bytes
  tempFrame.extd = 0;
  tempFrame.data_length_code = 8;
  tempFrame.data[0] = (temp1 >> 8) & 0xFF;  // High byte
  tempFrame.data[1] = temp1 & 0xFF;         // Low byte
  tempFrame.data[2] = (temp2 >> 8) & 0xFF;  // High byte
  tempFrame.data[3] = temp2 & 0xFF;        // Low byte
  tempFrame.data[4] = 0xAA;                   //// Best to use 0xAA (0b10101010) instead of 0
  tempFrame.data[5] = 0xAA;                   //  CAN works better this way as it needs
  tempFrame.data[6] = 0xAA;                   //to avoid bit-stuffing
  tempFrame.data[7] = 0xAA;
  // Accepts both pointers and references
  ESP32Can.writeFrame(tempFrame);  // timeout defaults to 1 ms

}


void loop() {

  mcp9600_get_temperature(&mcp9600_temp);
  int_mcp9600_temp = round(mcp9600_temp * 100);

  Serial.print("mcp9600_temp: ");
  Serial.print(mcp9600_temp);
  Serial.println(" C");
  delay(10);
  pt100_temp = PT100.readTemperature(HighTemperaturePin);  //Get temperature
  float_pt100_temp=pt100_temp/10;
  Serial.print("PT100:  ");
  Serial.print(float_pt100_temp);
  Serial.println(" C");

  send_measurement_can(int_mcp9600_temp,pt100_temp);
  delay(1000*10 );
}

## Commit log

2024-12-03 information docs for sensors and esp32
2024-12-05 lib files for sensors
2024-12-09 sketch for 2 sensors: pt100, thermocuple with shematics + datasheet
    [pt100 Index table.xls]
2024-12-09 sketch bme680 schematics and datasheets
2024-12-10 Update sensor_node_2_environmental_over_wifi.ino
    tested publish to public mqtt broker
    [sensor_node_2_environmental_over_wifi.ino]
2024-12-10 Update sensor_node_2_environmental_over_wifi.ino
    send text or json formatted data from the BME380 to an mqtt broker
    [sensor_node_2_environmental_over_wifi.ino]
2024-12-10 add instruction of setup RasberyPi and schematics
2024-12-11 fix node 2 mqtt to connect to rasberyPI mqtt and not mqtts as before -no need it in local context
    [sensor_node_2_environmental_over_wifi.ino]
2024-12-12 sync with sensor node_2
2024-12-17 setup Pt1000 for working with ESP32
2025-01-10 Stand to mount lcd and buttons
    [LCD.stp, stand.3mf, stand.FCStd]
2025-01-13 misc update on the stand after printing
    [LCD.stp, stand.3mf, stand.FCStd]
2025-01-13 add lcd, buttons and logic to handle them
2025-01-15 fix CAN Rx pin, pt100 reading to float
    [sensor_node_3_temperature_over_can.ino]
2025-01-15 fix minnor print issue
    [sensor_node_3_temperature_over_can.ino]
